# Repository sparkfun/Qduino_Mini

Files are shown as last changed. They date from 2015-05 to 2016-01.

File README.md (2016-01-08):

***NOTE:*** *This product was a Kickstarter product. If you are looking for more up-to-date info and the current version of this board, please check out the [current (Storefront) version](https://github.com/sparkfun/Qduino_Mini_SFE), [Qduino Mini product page](https://www.sparkfun.com/products/13614), or the [Arduino board support and library](https://github.com/sparkfun/Arduino_Boards).*

Qduino Mini

The Qduino Mini is *perfect* to embed in your electronics projects, it's super small, inexpensive, has a battery connector & charger built-in, & a fuel gauge that can tell you when to charge the battery!

The **Qduino Mini is Arduino-compatible & 100% open source, hardware and software** meaning that making and programming your first circuit is a breeze.  Hardware is hard, so we decided to make it a little bit easier.  All of the design files, including EAGLE board files, schematic, and code have been released under an open source license.  Here's what it includes:

* **Battery Charger Circuit** - just plug in USB and it charges the battery with the auto switching circuit - there's no extra charger needed & no digging the battery out of your project so you can charge & program at the same time over USB!
* **Battery Fuel Gauge** - guessing on when your project runs out of juice?  We've got you covered - we have a simple monitor library for your battery so you can remind yourself when it needs a little extra juice.
* **Ultra small, Ultra thin, Ultra light** - The Qduino Mini itself is 0.8in x 1.5in (2cm x 3.9cm) & 0.18oz (5 grams), perfect for quadcopters, drones or high altitude balloon projects.  Both the Qduino Mini and the batteries (LiPos) used to power the board fit are super compact & thin, just right for embedding in your projects.

######Tech Specs:

* **ATmega32U4 Processor** - Arduino Leonardo Compatible
* 32KB Flash Storage
* 2.5KB SRAM
* 1KB EEPROM
* 3.3V @ 8MHz
* 20 Digital I/O // 14 Dedicated
* 12 Analog Channels // 6 Dedicated
* 7 Digital I/O also PWM channels
* SPI, I2C, UART available
* Two RGB LEDs built-in - one for: Charge Status, TX, RX, and the * other user programmable
* **TPS78233** 3.3V 150mA Regulator
* **MCP73832** LiPo Battery Charger
* **MAX17048** LiPo Battery Fuel Gauge

The Qduino Mini is 100% made in the USA! Every board is made and quality tested at SparkFun Electronics, in Niwot, CO.

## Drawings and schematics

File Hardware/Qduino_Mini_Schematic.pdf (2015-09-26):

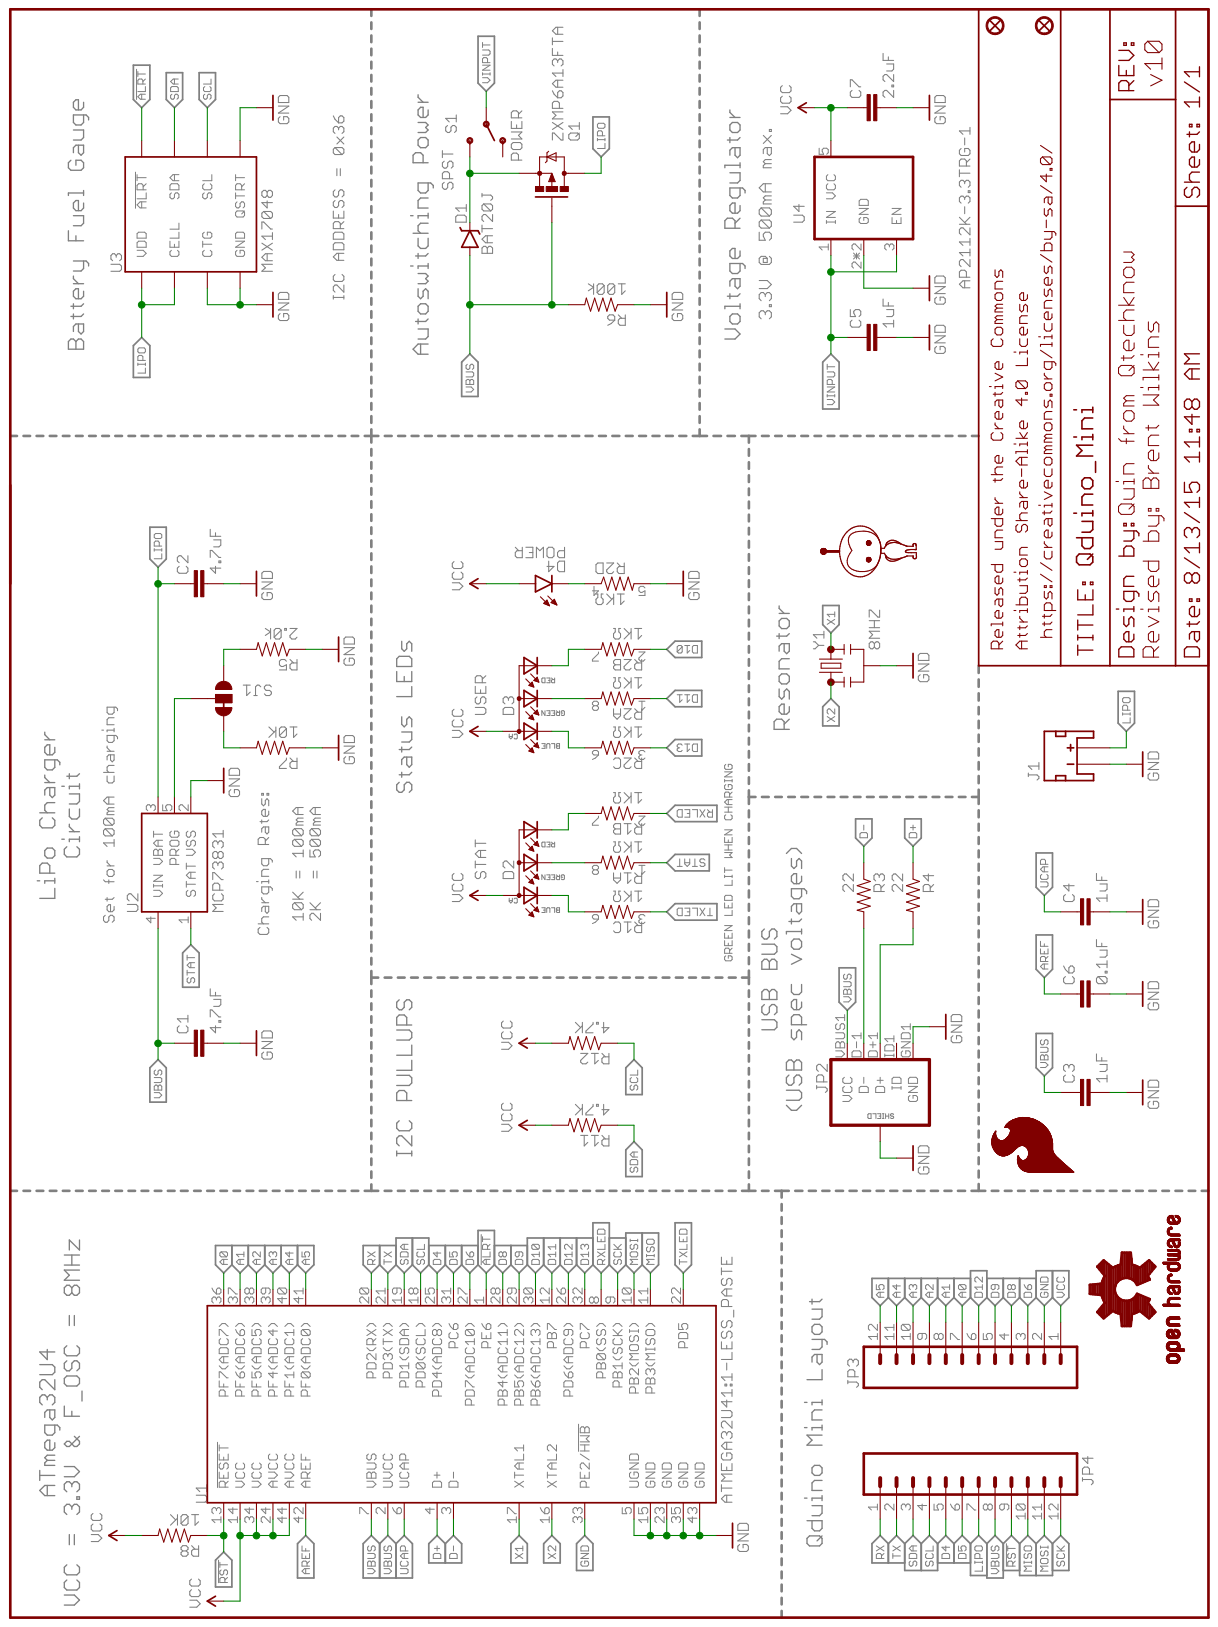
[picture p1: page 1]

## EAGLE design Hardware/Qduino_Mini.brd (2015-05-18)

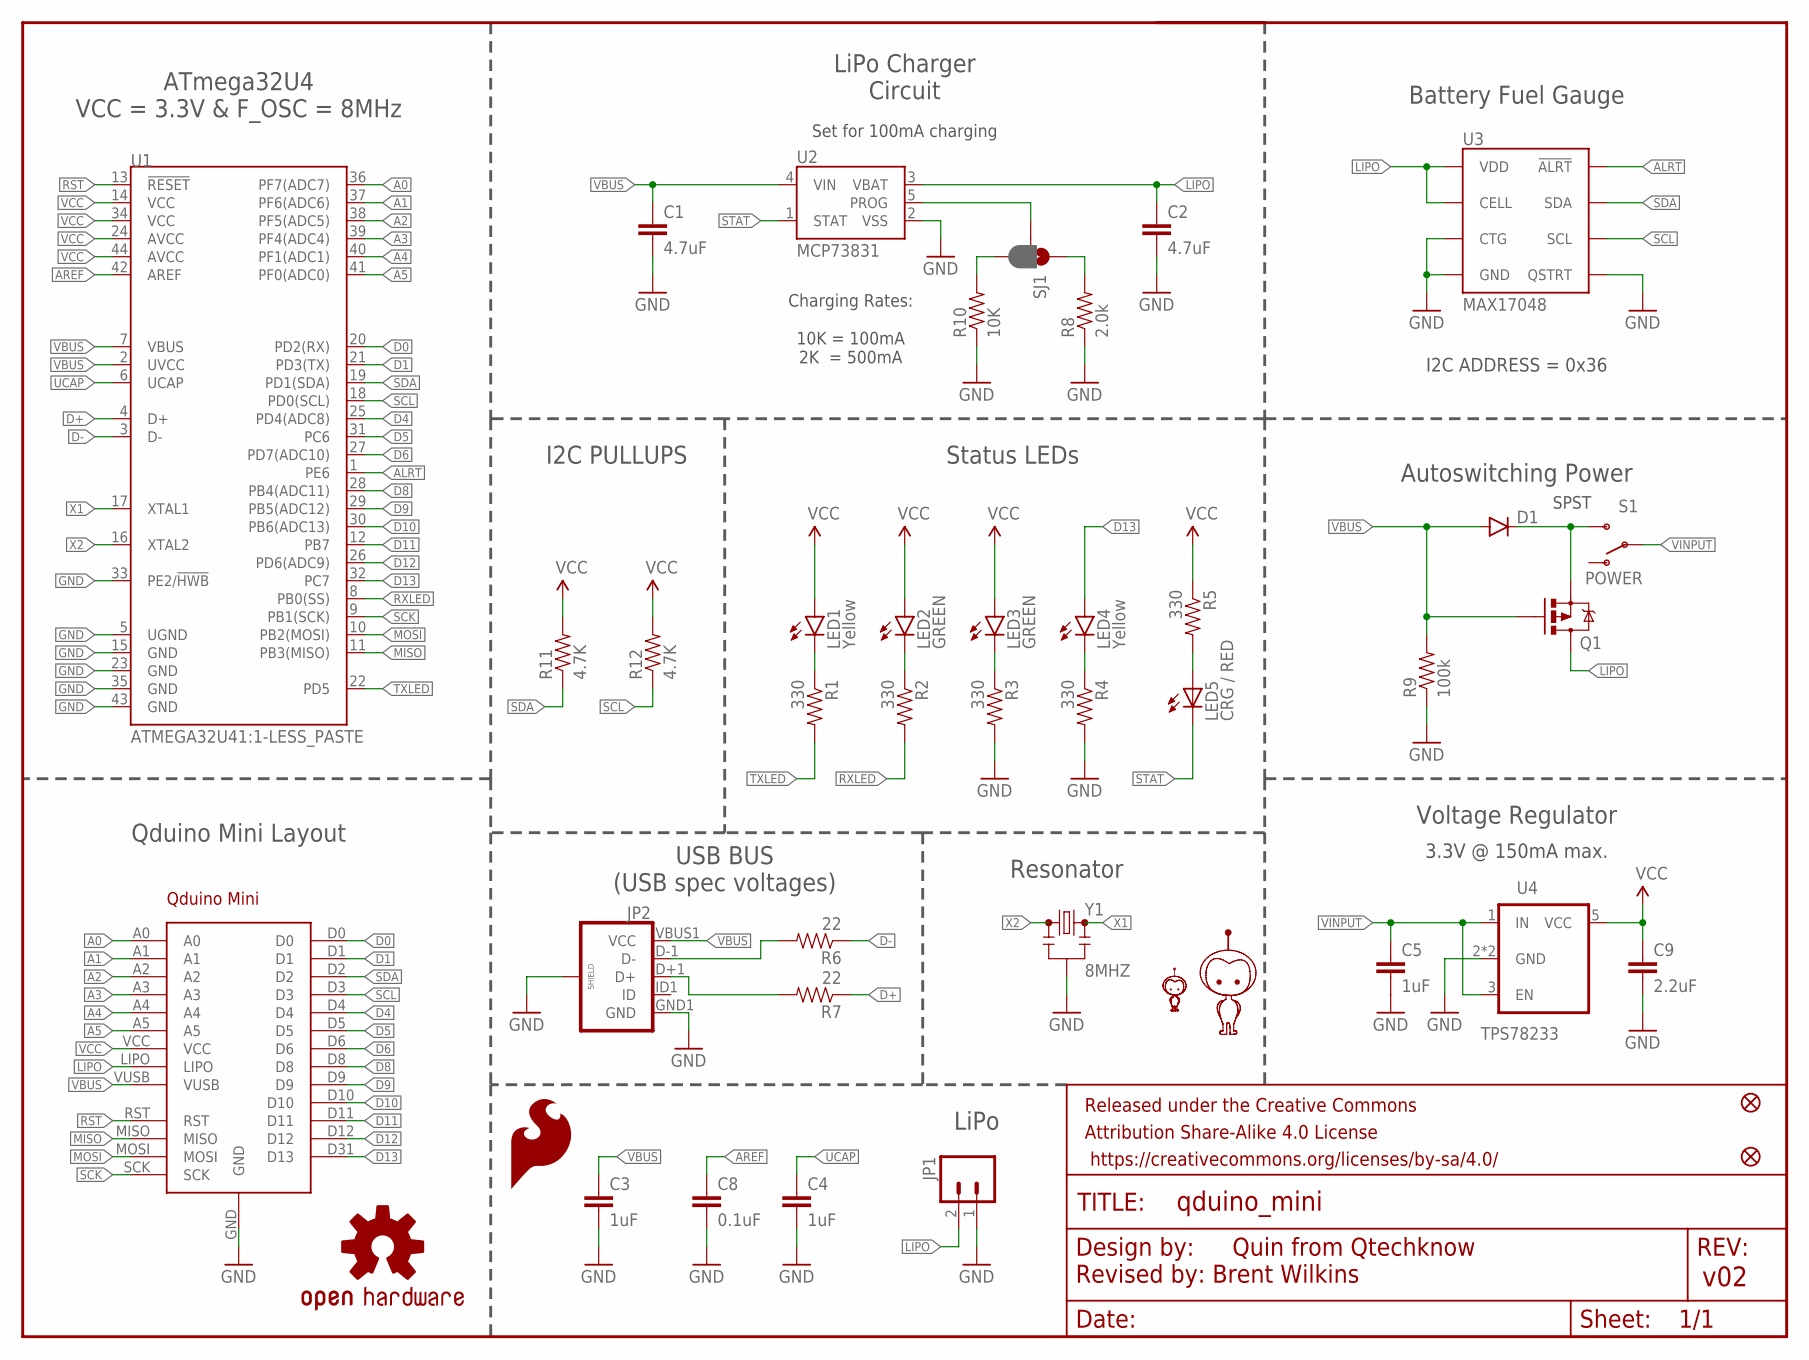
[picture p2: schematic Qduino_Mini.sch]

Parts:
C1, C2: 4.7uF; 0603-CAP
C3, C4, C5: 1uF; 0603-CAP
C8: 0.1uF; 0603-CAP
C9: 2.2uF; 0603-CAP
D1: 250mA/100V; SOD-323
FID5, FID6: FIDUCIAL1X2; FIDUCIAL-1X2
FRAME2: FRAME-LETTER; CREATIVE_COMMONS
JP1: LiPo; JST-2-SMD
JP2: USB_MICROB_PLUGCONN-11752; USB-B-MICRO-SMD_V03
LED1, LED4: Yellow; LED-0603
LED2, LED3: GREEN; LED-0603
LED5: CRG / RED; LED-0603
LOGO1: OSHW-LOGOS; OSHW-LOGO-S
LOGO2: SFE_LOGO_FLAME.1_INCH; SFE_LOGO_FLAME_.1
Q1: PFET; SOT23-3
R1, R2, R3, R4, R5: 330; 0603-RES
R6, R7: 22; 0603-RES
R8: 2.0k; 0603-RES
R9: 100k; 0603-RES
R10: 10K; 0603-RES
R11, R12: 4.7K; 0603-RES
S1: POWER; SWITCH-SPST-SMD-A
SJ1: JUMPER-PAD-3-2OF3_NC_BY_PASTE; PAD-JUMPER-3-2OF3_NC_BY_PASTE_YES_SILK_FULL_BOX
U1: ATMEGA32U41:1-LESS_PASTE; QFN-44-NOPAD_1:1-LESS_PASTE
U2: MCP73831; SOT23-5
U3: MAX17048; DFN-8
U4: TPS78233; SOT23-5
U5: MIGHTYQ-L-SILK; LOGO-LARGE-SILK
U6: MIGHTYQ-S-SILK; LOGO-SMALL-SILK
U7: DNP; QDUINO_MINI_V15
Y1: 8MHZ; RESONATOR-SMD

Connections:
A0: U1.36 (PF7(ADC7)), U7.A0
A1: U1.37 (PF6(ADC6)), U7.A1
A2: U1.38 (PF5(ADC5)), U7.A2
A3: U1.39 (PF4(ADC4)), U7.A3
A4: U1.40 (PF1(ADC1)), U7.A4
A5: U1.41 (PF0(ADC0)), U7.A5
ALRT: U1.1 (PE6), U3.P$5 (!ALRT)
AREF: C8.1, U1.42 (AREF)
D0: U1.20 (PD2(RX)), U7.D0
D1: U1.21 (PD3(TX)), U7.D1
D4: U1.25 (PD4(ADC8)), U7.D4
D5: U1.31 (PC6), U7.D5
D6: U1.27 (PD7(ADC10)), U7.D6
D8: U1.28 (PB4(ADC11)), U7.D8
D9: U1.29 (PB5(ADC12)), U7.D9
D10: U1.30 (PB6(ADC13)), U7.D10
D11: U1.12 (PB7), U7.D11
D12: U1.26 (PD6(ADC9)), U7.D12
D13: LED4.A, U1.32 (PC7), U7.D31 (D13)
D+: R7.1, U1.4 (D+)
D-: R6.1, U1.3 (D-)
GND: C1.2, C2.2, C3.2, C4.2, C5.2, C8.2, C9.2, JP1.1, JP2.GND1 (GND), JP2.SHIELD1 (SHIELD), JP2.SHIELD2 (SHIELD), JP2.SHIELD3 (SHIELD), R3.2, R4.2, R8.1, R9.1, R10.1, U1.5 (UGND), U1.15 (GND), U1.23 (GND), U1.33 (PE2/!HWB), U1.35 (GND), U1.43 (GND), U2.2 (VSS), U3.P$1 (CTG), U3.P$4 (GND), U3.P$6 (QSTRT), U3.P$9 (GND), U4.2 (GND), U4.4 (GND), U7.GND, Y1.2
INMOSFET: D1.C, Q1.2 (S), S1.3 (S)
LIPO: C2.1, JP1.2, Q1.3 (D), U2.3 (VBAT), U3.P$2 (CELL), U3.P$3 (VDD), U7.LIPO
MISO: U1.11 (PB3(MISO)), U7.MISO
MOSI: U1.10 (PB2(MOSI)), U7.MOSI
unnamed: LED1.C, R1.1
unnamed: LED2.C, R2.1
unnamed: LED5.A, R5.2
unnamed: LED4.C, R4.1
unnamed: R10.2, SJ1.3
unnamed: R8.2, SJ1.1
unnamed: LED3.C, R3.1
PROG: SJ1.2, U2.5 (PROG)
RST: U1.13 (!RESET), U7.RST
RXLED: R2.2, U1.8 (PB0(SS))
SCK: U1.9 (PB1(SCK)), U7.SCK
SCL: R12.1, U1.18 (PD0(SCL)), U3.P$7 (SCL), U7.D3
SDA: R11.1, U1.19 (PD1(SDA)), U3.P$8 (SDA), U7.D2
STAT: LED5.C, U2.1 (STAT)
TXLED: R1.2, U1.22 (PD5)
UCAP: C4.1, U1.6 (UCAP)
UD+: JP2.D+1 (D+), R7.2
UD-: JP2.D-1 (D-), R6.2
VBUS: C1.1, C3.1, D1.A, JP2.VBUS1 (VCC), Q1.1 (G), R9.2, U1.2 (UVCC), U1.7 (VBUS), U2.4 (VIN), U7.VUSB
VCC: C9.1, LED1.A, LED2.A, LED3.A, R5.1, R11.2, R12.2, U1.14 (VCC), U1.24 (AVCC), U1.34 (VCC), U1.44 (AVCC), U4.5 (VCC), U7.VCC
VINPUT: C5.1, S1.2, U4.1 (IN), U4.3 (EN)
X1: U1.17 (XTAL1), Y1.3
X2: U1.16 (XTAL2), Y1.1

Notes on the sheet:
Set for 100mA charging
USB BUS (USB spec voltages)
Resonator
Status LEDs
3.3V @ 150mA max.
SPST
ATmega32U4 VCC = 3.3V & F_OSC = 8MHz
Qduino Mini Layout
LiPo Charger Circuit
Battery Fuel Gauge
Voltage Regulator
Autoswitching Power
Charging Rates: 10K = 100mA 2K = 500mA
I2C PULLUPS
Revised by: Brent Wilkins
I2C ADDRESS = 0x36

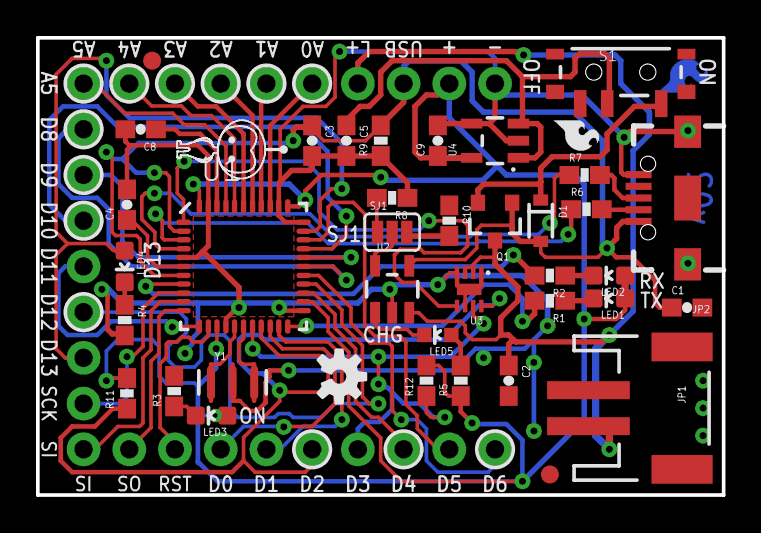
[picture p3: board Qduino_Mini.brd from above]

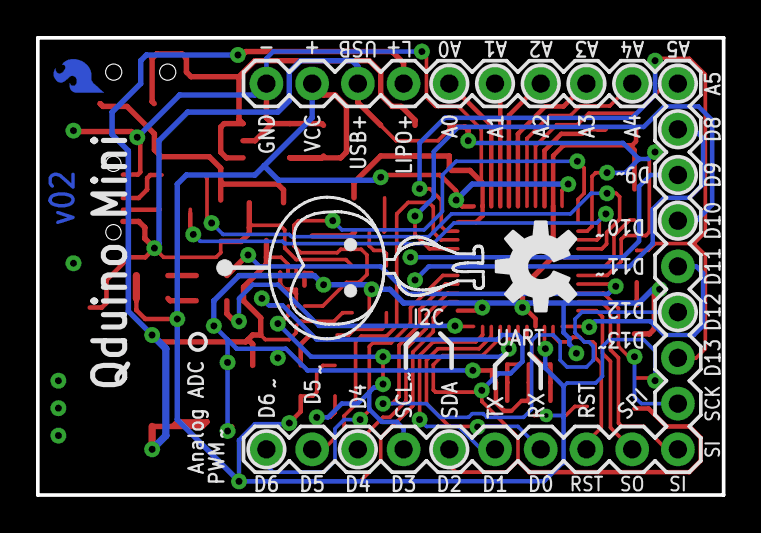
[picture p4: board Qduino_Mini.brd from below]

Board: 2 copper layers, 38.1 x 25.4 mm, 45 parts (3 on the bottom side), 49 nets.

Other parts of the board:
U$4: OSHW-LOGO-M
U$6: SFE-LOGO-FLAME-COPPER

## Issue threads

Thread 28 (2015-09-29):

How to use "Status" LED?

Flat-earth-academy, 2015-09-29:
Please let me know....

I have turned the red LED in the "Status" tri-color LED on and off with...

setup()
{
pinMode(17,OUTPUT);
}

loop()
{
digitalWrite(17,HIGH);
delay(400);
digitalWrite(17,LOW);
delay(400);
}

** Q1) Is that okay? (As long as I am not trying to use the SPI bus at the same time.)

** Q2) Would I be wanting to use the SPI bus unless I was changing the firmware in the Qduino?

===
I've RTFM... and determined that the blue LED in the Stat tri-color is driven by the ATmega32U's PD5... but I've failed to figure out how to use that as an output, or whether there might be consequences from doing it.

** Q3) How do I use PD5 as an output?
** Q4) Are there consequences for other Qduino functions?

BrentWilkins, 2015-09-29:
Before I directly answer your questions I'd like to ask if you can use the User LED instead?

MightyQ, 2015-09-29:
The stat LED is connected to RX TX and the charge status pin on the battery charger.  I'd recommend using the User RGB LED as Brent said because it is supported in the library and easier to use with the built in functions in the Qduino library

Flat-earth-academy, 2015-09-30:
Many thanks, both of you. Yes, of course, User LED would be first port of call... but, those other LEDs are THERE, are connected to the processor... are they destined to never do anything?

Flat-earth-academy, 2015-09-30:
Looking at "Q3", I thought maybe I ought to rephrase it...
"Is there a way to switch PD5 high and low? Can you anticipate any unintended consequences? I'm looking for something like "digitalWrite(D27,HIGH)", in a perfect world! (Or something else accessible with just "normal" Arduino code.)

Maybe you knew that. (^_^)

Flat-earth-academy, 2015-09-30:
The Qduino class's "begin()" does things to an interrupt handler, I believe, to make the ATmega "see" a signal on the fuel gauge chip's /ALRT o/p. Could/ should/ has that been made to ALSO turn the blue LED on, as part of the interrupt handler, independent of any code the "ordinary" programmer would need to write, apart from having done a begin() for a quduino-class object?

BrentWilkins, 2015-09-30:
The bootloader is based on the standard Caterina bootloader.  In Caterina.h an example of how the status LEDs are turned off is:
	#define TX_LED_OFF()	PORTD |= (1<<5)
	#define RX_LED_OFF()	PORTB |= (1<<0)
The TX & RX LEDs show the status of the transmit and receive hardware when communicating over USB.  This is baked into the bootloader.  You must be aware that they will toggle on you.  Maybe it won't matter in your use case.  If you really want to use them, the source code for the bootloader can be found in the files downloaded by the board manager.  It's possible to remove them from the bootloader, so you have full control.
I believe you can toggle them safely, but in certain states you might get something strange.  It probably works fine, but I haven't tested it.

I'm a bit confused by your statement about on Quin's begin method:
void qduino::begin()
{
  pinMode(13, OUTPUT);    // Blue user LED
  digitalWrite(13, HIGH);
  pinMode(11, OUTPUT);    // Green user LED
  digitalWrite(11, HIGH);
  pinMode(10, OUTPUT);    // Red user LED
  digitalWrite(10, HIGH);
}

While it could, his library doesn't use interrupts.

Flat-earth-academy, 2015-09-30:
Oh heck... sorry to reward your kind trouble-taking with a bad question!

The thing that caught my eye was in the fuelguage begin()...

void fuelGauge::begin()
{
  // Enable external interrupt for MAX17048 ALRT pin
  cli();  // Disable global interrupts while configuring
  DDRE  &= ~(_BV(6));   // Set PE6 as an input
  PORTE |= (_BV(6));    // Turn on pull-up for PE6
  EICRB = (EICRB & ~(1<<ISC60)) | (1<<ISC61); // Set the interrupt type falling
  EIMSK |= (1<<INT6);   // Activate the interrupt
  sei();  // Enable global interrupts

  reset();
  performCommand(MAX1704_QUICK_START, 0x00); // aka quickStart();
}

... maybe that's not the ATmega's interrupt, as I was guessing. (My grasp of interrupt handling goe back to when I decided to avoid them with 6802 based designs... but maybe time I learned how to use them, for the Qduino!)

====
(On the LED on D17: I will go away and ponder... plenty of info now received, understood.)

====
Would it be fair to say that the red and blue LEDs in Stat might best be left alone IF using the USB link, say to communicate with the serial monitor... but that they (the LEDs) can be turned on/ off safely by a program that is not using the USB channel for anything? (Their state undetermined during programming, and program updating... but "user determined" while program is running?)

BrentWilkins, 2015-09-30:
No such thing as a bad question.
That's embarrassing.  That ISR code that you have there was me playing around.  I never meant to commit that.  If you update (Install) again in the board manager it will go away and you will get Quin's version.  I started the ISR methods and realized they might be confusing.  At least to some degree I was right!
I haven't tested yet, but I would hope that you can use the LEDs for whatever you want and that the bootloader would configure them they way it needs them every time it tries to use them.

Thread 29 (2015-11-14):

attachinterrupt compile error

JonathanFHill, 2015-11-14:
when attempting to use AttachInterrupt

C:\Users\Jonathan\AppData\Local\Temp\build4346342965207304710.tmp/core.a(WInterrupts.c.o): In function `__vector_7':
C:\Program Files (x86)\Arduino\hardware\arduino\avr\cores\arduino/WInterrupts.c:272: multiple definition of `__vector_7'
Qduino\Qduino.cpp.o:C:\Users\Jonathan\AppData\Roaming\Arduino15\packages\Qduino Mini\hardware\avr\1.0.3\libraries\Qduino/Qduino.cpp:315: first defined here
collect2.exe: error: ld returned 1 exit status
Error compiling.

BrentWilkins, 2015-11-18:
Did the suggestion I posted on Hackster of updating to the current version work for you? You are running 1.0.3, and the current version is 1.0.8.

JonathanFHill, 2015-11-18:
Yes thank you. Works perfectly. Please mark as resolved.

Sent from Outlook

On Wed, Nov 18, 2015 at 8:50 AM -0800, "Brent Wilkins" <notifications@github.com> wrote:

Did the suggestion I posted on Hackster of updating to the current version work for you? You are running 1.0.3, and the current version is 1.0.8.

—
Reply to this email directly or view it on GitHub.

Closed 2015-11-18.

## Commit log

2015-03-10 testing out a reduced sized die pad to provide the recommended mechanical support, but with low pad to pin short likelihood
    [Qduino_Mini.brd, Qduino_Mini.sch]
2015-03-10 Rerouted grounds under IC
    Cleaned the ground traces under IC up. Passes DRC now too.
    [Qduino_Mini.brd]
2015-03-10 Fixed a y junction
    being picky
    [Qduino_Mini.brd]
2015-03-19 Used version of MCP73831 in current library, rather than legacy library. No real change.
    [Qduino_Mini.brd, Qduino_Mini.sch]
2015-04-07 Updated capactior ID
    [Qduino_Mini.brd, Qduino_Mini.sch]
2015-04-22 Moved battery over to make rework easier. In the process moved the power LED to the middle. Also fixed RX/TX lines(D0/D1)
    [Qduino_Mini.brd, Qduino_Mini.sch]
2015-04-22 Incremented version #
    [Qduino_Mini.brd, Qduino_Mini.sch]
2015-04-23 Added info on safe voltages & oscillator speeds
    [Qduino_Mini.sch]
2015-04-24 Added I2C address to schematic for fuel gauge. No change to PCB
    [Qduino_Mini.sch]
2015-05-18 Added 'IC-' prefix to the attriburtes of a part
    [Qduino_Mini.brd, Qduino_Mini.sch]
2015-09-26 Added a pdf of the schematic
2015-12-22 Ignored table 28-3 in datasheet about the extended fuse bits. Changing bits 5:4 to 0's as a workaround to bug in AVRDUDE (https://savannah.nongnu.org/bugs/?21954).
2016-01-08 Added not to link to current version

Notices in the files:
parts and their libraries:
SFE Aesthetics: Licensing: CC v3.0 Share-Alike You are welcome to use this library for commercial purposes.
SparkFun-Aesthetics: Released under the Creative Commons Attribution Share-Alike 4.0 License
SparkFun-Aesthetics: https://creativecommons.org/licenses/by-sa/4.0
